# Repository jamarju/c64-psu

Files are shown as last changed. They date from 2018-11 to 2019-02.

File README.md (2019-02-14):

# C64 power supply unit

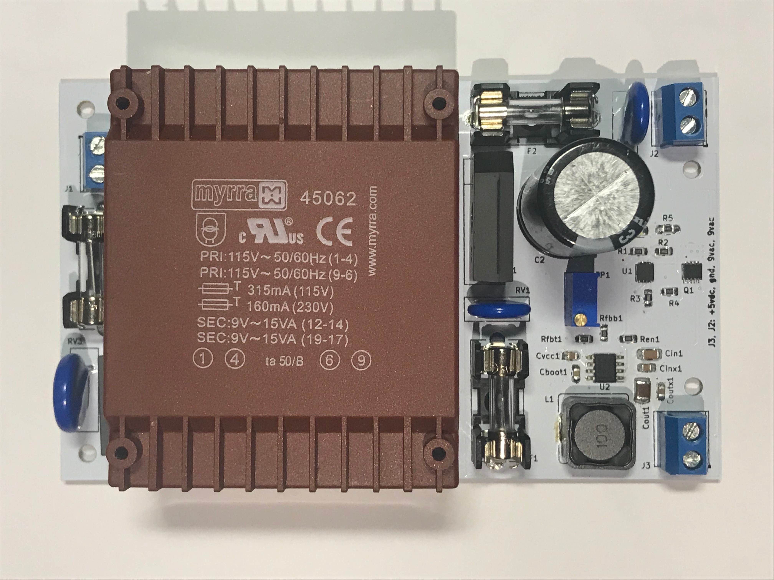
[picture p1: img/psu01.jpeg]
pcb view


This is a compact and efficient 9VAC/5VDC power supply for the Commodore 64 with the following features:

* 230VAC input (but easy to modify for 115VAC operation).
* 5 VDC output, adjustable, 1.75A max.
* 9 VAC output, 1.67A max.
* 6.5 VDC overvoltage protection (latching).
* Low VDC output ripple (<25 mV<sub>pp</sub> @1A).
* 2A overcurrent protection.
* Low heat dissipation.
* Mains overvoltage and noise suppresion.

## Building, warnings and recommendations

The kicad-project/gerbers folder contains gerber files ready for production. These are my recommended PCB specifications:

* 1.6 mm PCB thickness
* 2 oz copper thickness
* Min track / clearance: 8 mil

Beware there are three SMD components with thermal pads on the base that can't be easily soldered with a regular iron. You'll need **solder paste and an oven or a heat gun for these**.

## 110VAC operation

To work at 110 VAC, do these modifications to the schematic:

1. Connect the two primaries of TR1 in parallel instead of series:
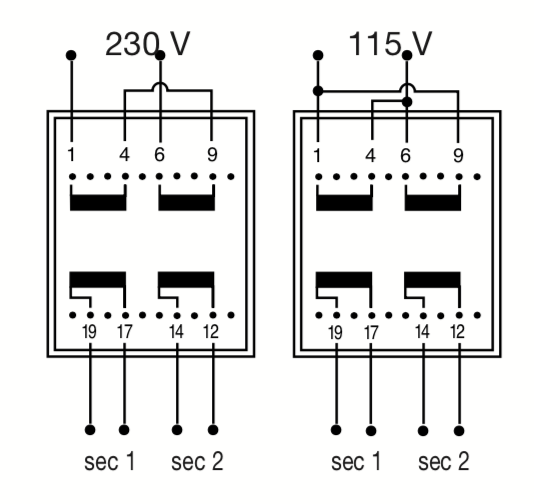
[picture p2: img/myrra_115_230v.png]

2. Replace RV3 (EPCOS 300 Vrms MOV) with EPCOS B72214S0151K101 (150 Vrms MOV).
3. Replace F3 (160 mA fuse) with 315 mA fuse.

## Adjusting 5VDC output

Start adjusting trimpot TP1 to get 5 VDC with no load.

Then check the voltage at the C64 input with the computer on. You should expect a bit less than 5V due to losses depending on the cable gauge and DIN connectors. Ideally you should aim at 5.0V but a bit of undervoltage (4.9V) appears to work okay on my C64 and will lower heat dissipation.

Output voltage can be adjusted in the [4.13V, 5.55V] range.

## Enclosure

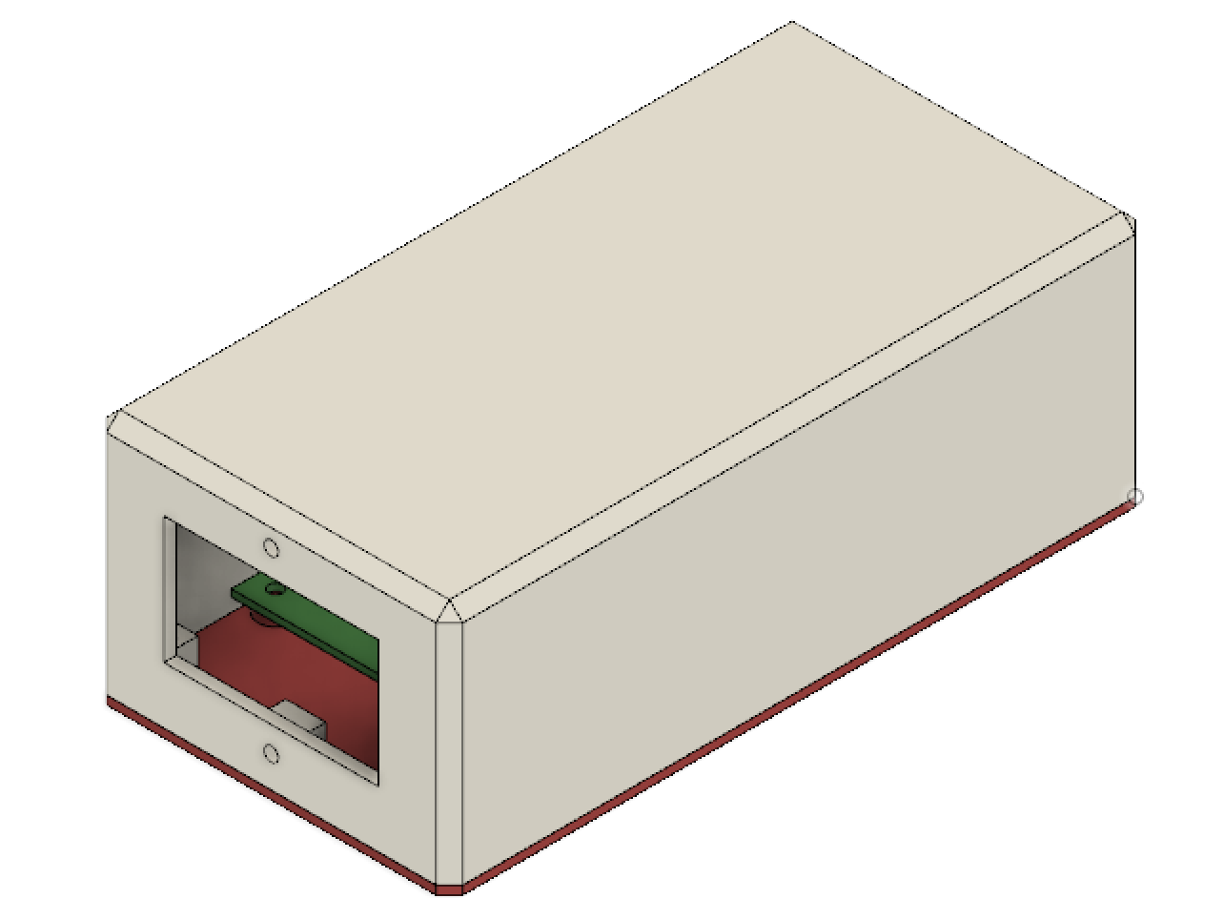
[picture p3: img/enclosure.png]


STLs and Fusion 360 project included in the enclosure/ folder. Sorry FreeCAD, I tried to keep this opensource but bodies in 0.17 are just not mature enough and doing this in 0.16 was too painful.

### Printing recommendations

* The bottom side can be printed bottom side flat on the printer bed without support.
* The top cover can be printed top side flat on the bed with supports everywhere.
* Material: I recommend PETG because of its higher melting temperature, great mechanical properties and low warping.
* I do not recommend PLA because of its low melting temperature.
* I do not recomment ABS either because of its high contraction ratio (= corner warp).

For the enclosure, in addition to the BOM components, you'll need:

* 6 x [Female quick disconnect 4.8 mm terminals](https://www.aliexpress.com/item/Free-shipping-100pcs-lot-4-8-insert-the-plug-spring-sheathed-wire-terminal-connector-cold-pressed/32593657279.html)
* 6 x [PCB male quick disconnect (aka spade) 4.8mm terminals](https://www.aliexpress.com/item/100pcs-4-8-Inserts-Plug-Spring-Terminal-PCB-Solder-lug-type-thickness-0-8mm-two-legs/32707189841.html) (these can replace the ones on the BOM and are much cheaper)
* 1 x [M12 PG7 strain relief](https://www.aliexpress.com/item/10pcs-Waterproof-M16-PG9-M12-PG7-Cable-Connectors-Spiral-Strain-Relief-Protector/32923675313.html)
* 1 x [Panel mount AC socket + rocking switch + fuse](https://www.aliexpress.com/item/Power-Rocker-Switch-IEC-3-Pin-320-C14-Inlet-Power-Sockets-Switch-Connector-Plug-10A-250V/32802047471.html)
* 1 x [4 cores, 5 meters 20 AWG cable](https://www.aliexpress.com/item/20-AWG-0-5MM2-RVV-2-3-4-5-6-7-8-10-12-14-16/32921926304.html)
* 1 x [7 pin male DIN connector (5 pcs minimum order)](https://www.aliexpress.com/item/5pcs-DIN-male-Plug-Connector-7-Pin-with-Plastic-Handle/32386538198.html)
* 10 x [M3x8 hex head bolts (100 units minimum order)](https://www.aliexpress.com/store/product/Free-Shipping-100pcs-Lot-Metric-Thread-DIN912-M3x8-mm-M3-8-mm-304-Stainless-Steel-Hex/3094064_32851042824.html)
* 10 x [M3 nuts (100 units min order)](https://www.aliexpress.com/item/Free-shipping-100pcs-lot-Metric-thread-DIN934-M3-304-Stainless-Steel-Hex-Nuts/32405600179.html)

### Cable length

I recommend keeping the C64-side cable as short and thick as possible. I recommend 20 AWG, 1 meter long wires.

The expected loss over 1 meter of 20 AWG wire at 5VDC and 1A is 33 mV per leg or 67 mV round trip.

## Schematic and protective measures



This PSU uses a 9VAC, 30VA dual secondary (15 VA + 15 VA) transformer that provides up to 1.67 amps on each secondary.

The regulator is a TI LMR33630 switching DC/DC step down converter with a switching frequency ~400 KHz and a peak efficiency of 93%.

To prevent an overvoltage situation due to failure of the swithing regulator or the feedback network, a MAX6399 voltage supervisor is used to control a high side P-channel MOSFET at the input of the switcher. When an overvoltage condition (V<sub>out</sub> >6.5V) is detected, the MAX6399 pulls the gate of the MOSFET down and cuts the regulator input until the power is completely removed from the unit.

The MAX6399 also provides undervoltage protection for clean startup of the switcher.

In addition to the over/undervoltage supervisor 3 varistors (MOVs) provide surge protection on the primary and both secondaries and 3 fuses prevent prolonged overcurrent condition on both sides of the transformer. The switcher itself also has an instant overcurrent protection above 3A.

## Tests

### Output ripple

Test conditions: V<sub>out</sub>=5.1V, I<sub>out</sub>=1A.

* Low frequency ripple: <20mV<sub>pp</sub>

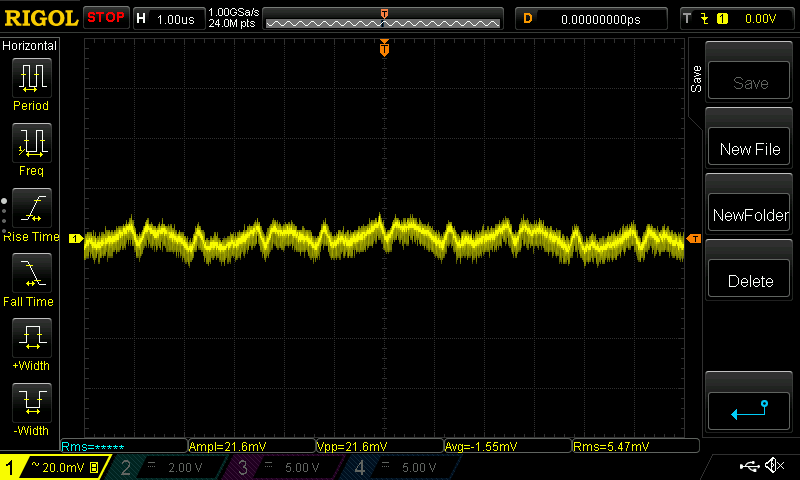
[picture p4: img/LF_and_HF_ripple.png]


### Overvoltage protection

Overvoltage protection voltage threshold set at V<sub>out</sub> >= 6.53V via R1/R2 divider.

Test conditions: shorted feedback input of LMR33630 to GND during normal operation at V<sub>out</sub>=5.1V, I<sub>out</sub>=1A.

@ 100 us per division:

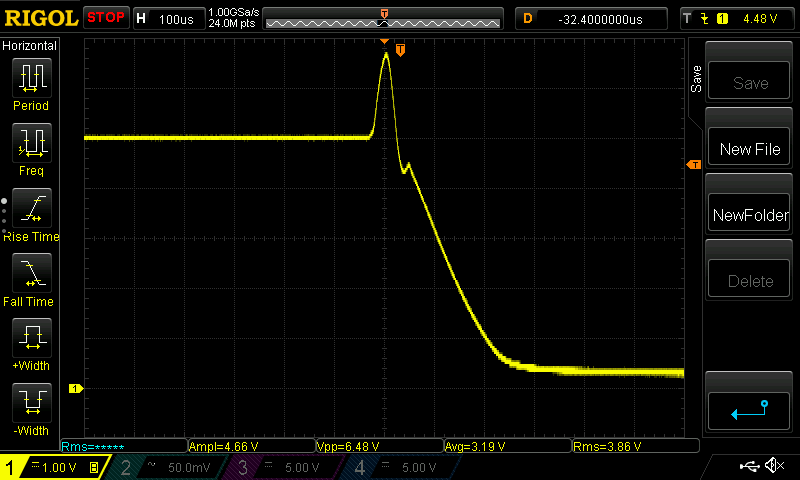
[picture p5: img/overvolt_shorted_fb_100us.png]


@ 10 us per division:

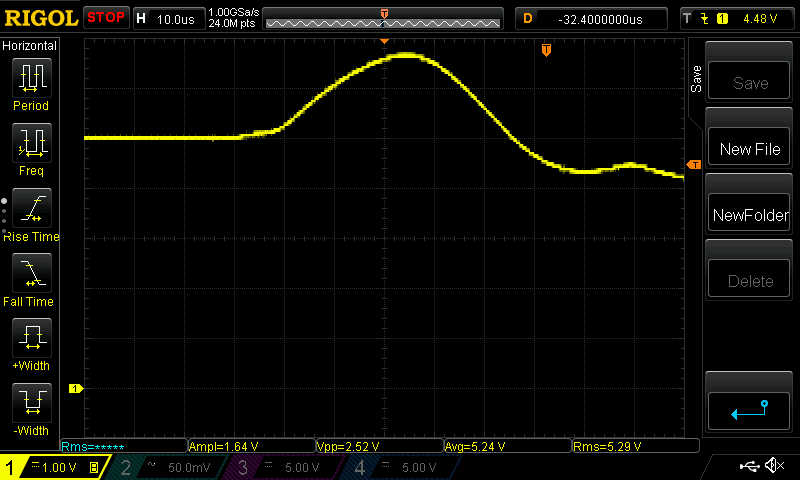
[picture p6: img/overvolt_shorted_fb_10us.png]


### Startup overshoot

Nominal V<sub>out</sub>: 5.10V
Overshoot: 5.36V (<10 ms)

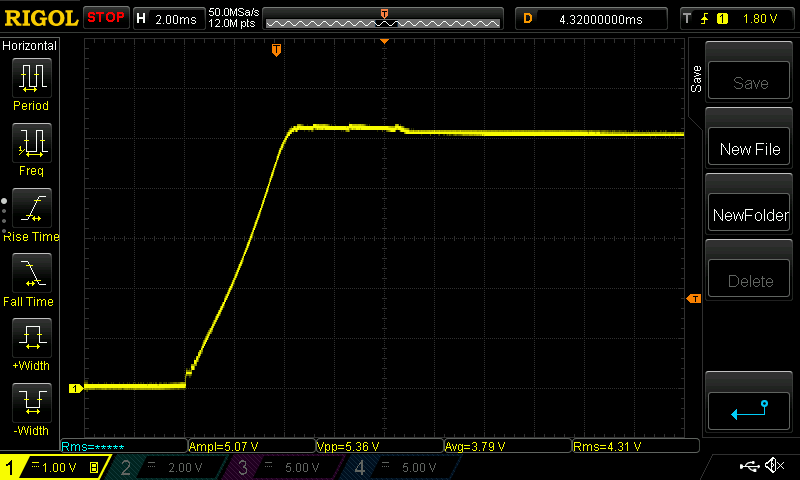
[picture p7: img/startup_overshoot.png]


### Power-ok and V<sub>out</sub> ramp-up

Undervoltage protection voltage threshold set at Vin <= 6.81V via R3/R4 divider.

* Yellow: V<sub>out</sub>
* Cyan: MAX6399 Power OK output (LMR33630 ENABLE input)

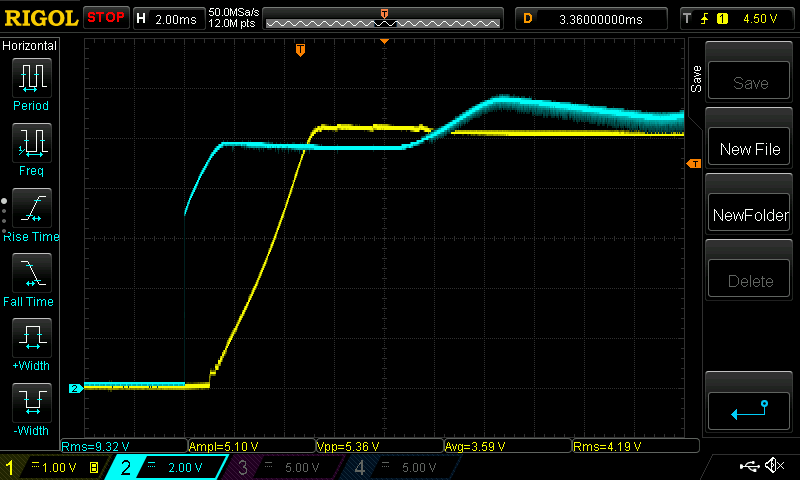
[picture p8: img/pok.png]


## TODO

* Actually test that this doesn't blow anything up. Tests should include at least:
  * Thermal behavior
  * Undervoltage POK (both edges)
  * Secondary-primary noise coupling
  * EMI emissions

## License

CC-BY-NC-SA (Attribution-NonCommercial-ShareAlike).

See LICENSE.txt for details.

Please do not mass (?) produce this without my permission.



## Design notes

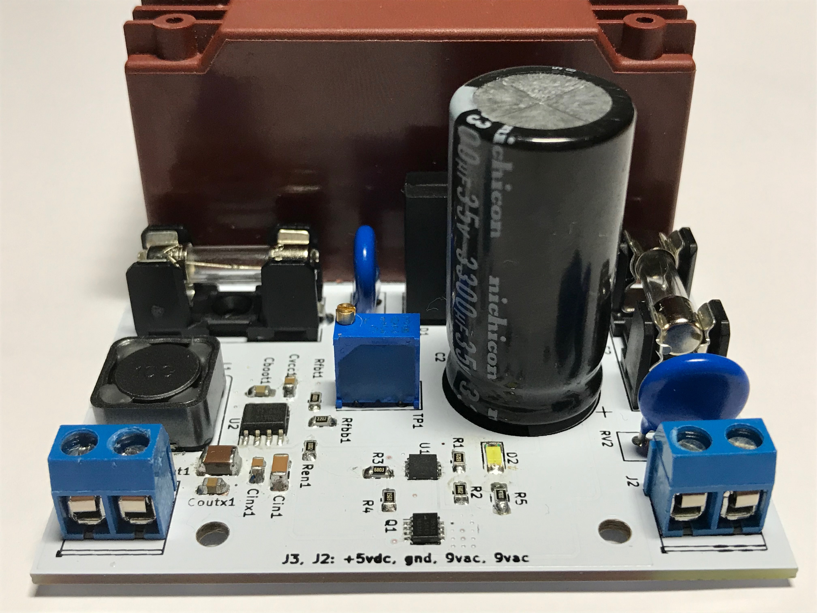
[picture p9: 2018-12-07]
img/psu04.jpeg

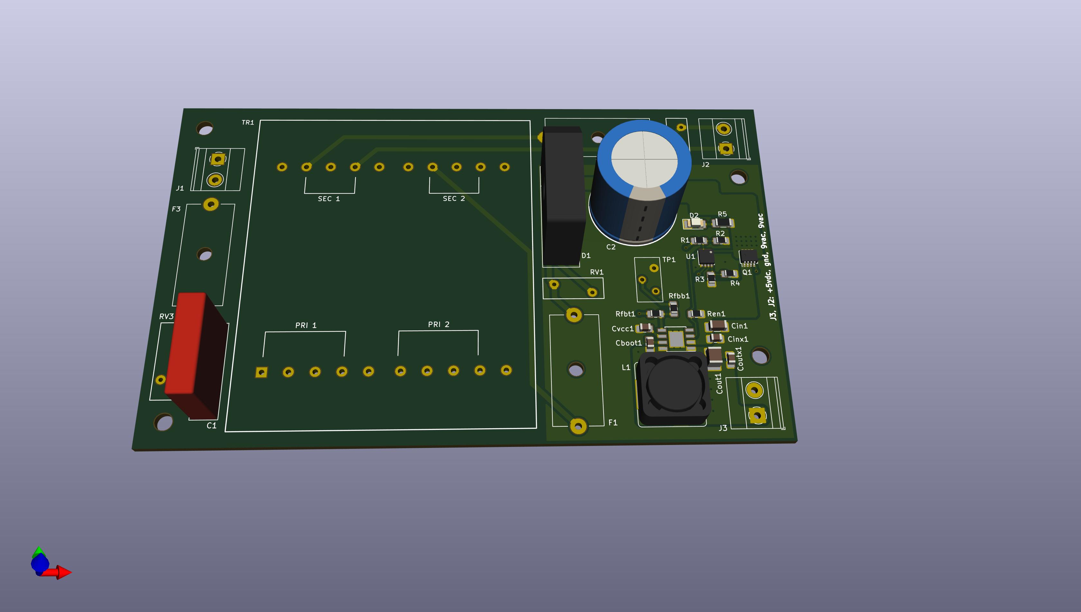
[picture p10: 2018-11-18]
img/render01.jpg

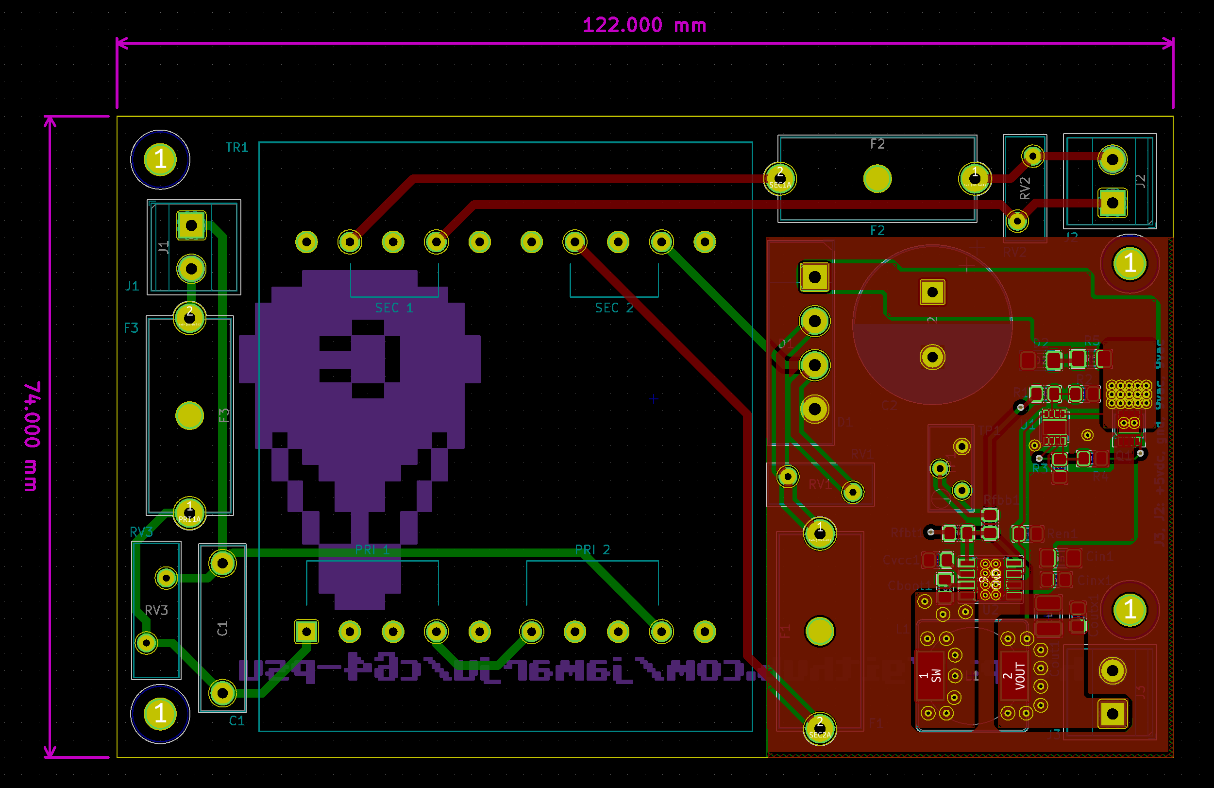
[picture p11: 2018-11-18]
img/pcb01.png

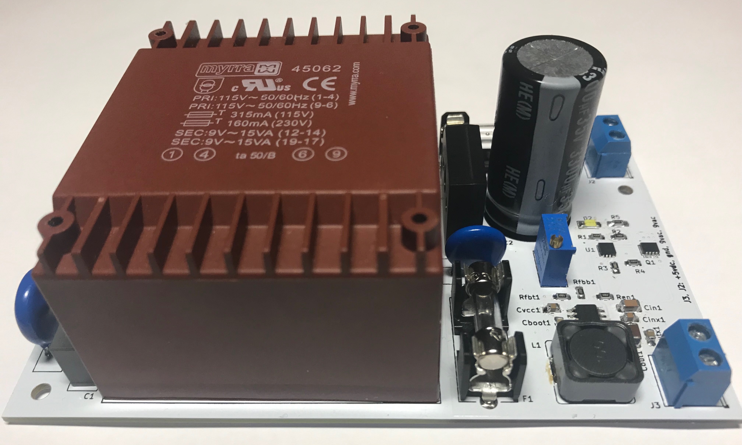
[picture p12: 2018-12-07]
img/psu02.jpeg

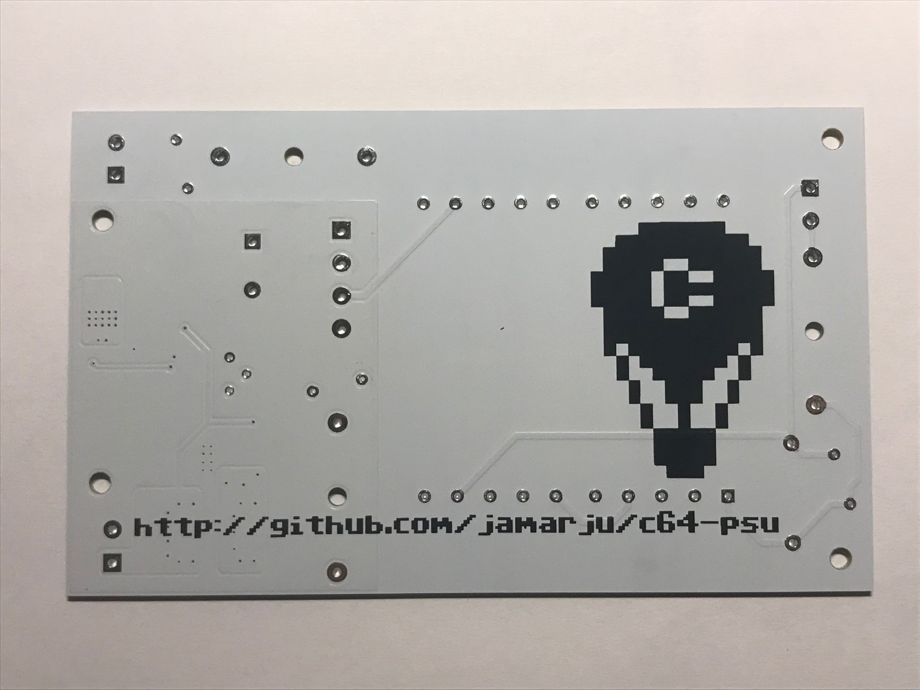
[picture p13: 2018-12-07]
img/psu03.jpeg

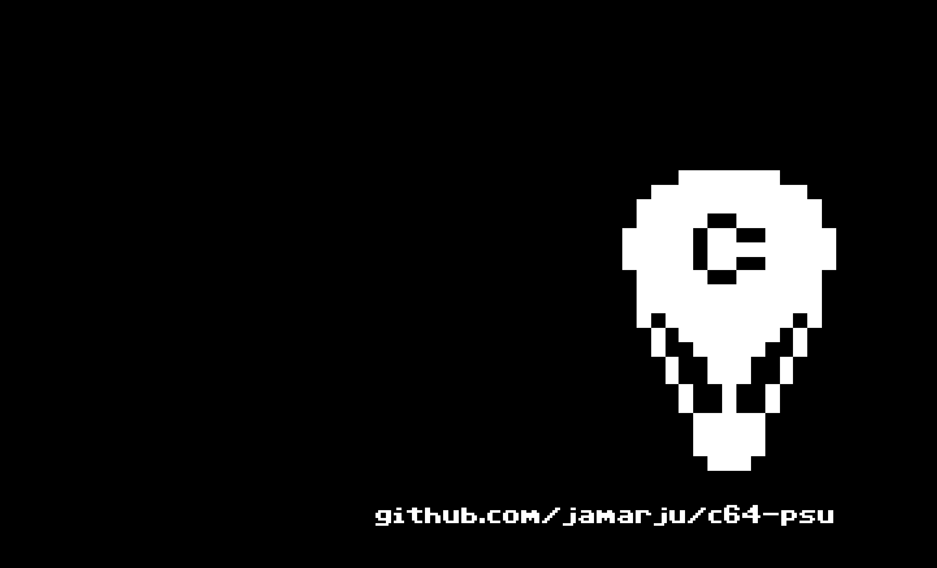
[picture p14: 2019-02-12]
art/linkballoon.png

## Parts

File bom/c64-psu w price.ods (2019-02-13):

Reference | Value | Footprint | Datasheet | Mfr | MfrCode | MouserCode | FarnellCode | Price
F2 | 1.67A | c64-psu:20mm fuse |  | Bel | 5ST 1.6-R | 530-5ST1.6-R |  | 0,172 €
F3 | 1.67A | c64-psu:20mm fuse |  | Bel | 5ST 1.6-R | 530-5ST1.6-R |  | 0,172 €
D1 | KBU8B | Diode_THT:Diode_Bridge_Vishay_KBU |  | GeneSiC | KBU8B | 905-KBU8B |  | 1,320 €
L1 | 10u | Inductor_SMD:L_Bourns_SRR1260 |  | Bourns | SRR1260-100M | 652-SRR1260-100M |  | 0,825 €
Rfbt1 | 100k | Resistor_SMD:R_0805_2012Metric_Pad1.15x1.40mm_HandSolder |  | Bourns | CR0805-FX-1003ELF | 652-CR0805FX-1003ELF |  | 0,013 €
Cout1 | 68u | Capacitor_SMD:C_1210_3225Metric_Pad1.42x2.65mm_HandSolder |  | TDK | C3225X5R0J686M200AC | 810-C3225X5R0J686M |  | 1,290 €
C2 | 3300u | Capacitor_THT:CP_Radial_D18.0mm_P7.50mm |  | Nichicon | UHE1V332MHD6 | 647-UHE1V332MHD6 |  | 2,180 €
U1 | LMR33630A | Package_SO:TI_SO-PowerPAD-8_ThermalVias |  | TI | LMR33630ADDAR | 595-LMR33630ADDAR |  | 3,210 €
Cboot1 | 100n | Capacitor_SMD:C_0805_2012Metric_Pad1.15x1.40mm_HandSolder |  | Yageo | CC0805KRX7R9BB104 | 603-CC805KRX7R9BB104 |  | 0,068 €
Rfbb1 | 22K | Resistor_SMD:R_0805_2012Metric_Pad1.15x1.40mm_HandSolder |  | Bourns | CR0805-FX-2202ELF | 652-CR0805-FX2202ELF |  | 0,013 €
Coutx3 | 1u | Capacitor_SMD:C_0805_2012Metric_Pad1.15x1.40mm_HandSolder |  | Murata | GRM21BR71A105KA01L | 81-GRM40X105K10L |  | 0,128 €
Cvcc1 | 1u | Capacitor_SMD:C_0805_2012Metric_Pad1.15x1.40mm_HandSolder |  | KEMET | C0805C105K8PACTU | 80-C0805C105K8P |  | 0,208 €
Cin1 | 10u | Capacitor_SMD:C_1206_3216Metric_Pad1.42x1.75mm_HandSolder |  | TDK | C3216X6S1V106K160AC | 810-C3216X6S1V106K6A |  | 0,374 €
Cinx1 | 220n | Capacitor_SMD:C_0805_2012Metric_Pad1.15x1.40mm_HandSolder |  | KEMET | C0805C224K5RACTM | 80-C0805C224K5RACTM |  | 0,111 €
F1 | 160mA | c64-psu:20mm fuse |  | Bel | 5ST 160-R | 530-5ST160-R |  | 0,172 €
RV1 | S14K300 | Varistor:RV_Disc_D15.5mm_W5.2mm_P7.5mm |  | EPCOS / TDK | B72214S301K101 | 871-B72214S301K101 |  | 0,326 €
C1 | 10n | Capacitor_THT:C_Rect_L19.0mm_W5.0mm_P15.00mm_MKS4 |  | KEMET | R46KI21004001K1 | 80-R46KI21004001K1 |  | 0,199 €
RV3 | S10K20 | Varistor:RV_Disc_D12mm_W4.5mm_P7.5mm |  | EPCOS / TDK | B72210S200K101 | 871-B72210S200K101 |  | 0,304 €
RV2 | S10K20 | Varistor:RV_Disc_D12mm_W4.5mm_P7.5mm |  | EPCOS / TDK | B72210S200K101 | 871-B72210S200K101 |  | 0,304 €
TRIM1 | 10K | Potentiometer_THT:Potentiometer_Bourns_3296Y_Vertical |  | Bourns | PV36Y103C01B00 | 81-PV36Y103C01B00 |  | 0,969 €
TR1 | Myrra_UI_39_TRF | c64-psu:Myrra UI 39 trf |  | Myrra | UI 39 |  | 1777965 | 11,900 €
R2 | 820k | Resistor_SMD:R_0805_2012Metric_Pad1.15x1.40mm_HandSolder |  | Bourns | CR0805-FX-8203ELF | 652-CR0805FX-8203ELF |  | 0,013 €
R4 | 68k | Resistor_SMD:R_0805_2012Metric_Pad1.15x1.40mm_HandSolder |  | Bourns | CR0805-FX-6802ELF | 652-CR0805FX-6802ELF |  | 0,013 €
U2 | MAX6399 | Package_DFN_QFN:DFN-8-1EP_3x3mm_P0.65mm_EP1.55x2.4mm |  | Maxim | MAX6399ATA+T | 700-MAX6399ATAT |  | 2,240 €
R3 | 680k | Resistor_SMD:R_0805_2012Metric_Pad1.15x1.40mm_HandSolder |  | Bourns | CR0805-FX-6803ELF | 652-CR0805FX-6803ELF |  | 0,013 €
Ren1 | 10k | Resistor_SMD:R_0805_2012Metric_Pad1.15x1.40mm_HandSolder |  | Bourns | CR0805-FX-1002ELF | 652-CR0805FX-1002ELF |  | 0,013 €
R5 | 150k | Resistor_SMD:R_0805_2012Metric_Pad1.15x1.40mm_HandSolder |  | Bourns | CR0805-FX-1503ELF | 652-CR0805FX-1503ELF |  | 0,065 €
R1 | 4K7 | Resistor_SMD:R_1206_3216Metric_Pad1.42x1.75mm_HandSolder |  | Bourns | CR1206-FX-4701ELF | 652-CR1206FX-4701ELF |  | 0,013 €
Q1 | N-MOS | c64-psu:LFPAK33-PSMN7R5-30MLD |  | Nexperia | PSMN7R5-30MLD | 771-PSMN7R5-30MLDX |  | 0,338 €
XF3 | 1.67A | Fuse:Fuseholder_Cylinder-5x20mm_Schurter_0031_8201_Horizontal_Open |  | Schurter | 0031.8201 | 693-0031.8201 |  | 0,466 €
XF2 | 1.67A | Fuse:Fuseholder_Cylinder-5x20mm_Schurter_0031_8201_Horizontal_Open |  | Schurter | 0031.8201 | 693-0031.8201 |  | 0,466 €
XF1 | 160 mA | Fuse:Fuseholder_Cylinder-5x20mm_Schurter_0031_8201_Horizontal_Open |  | Schurter | 0031.8201 | 693-0031.8201 |  | 0,466 €
D2 | LED | LED_SMD:LED_1206_3216Metric_Pad1.42x1.75mm_HandSolder |  | Any | Aliexpress: '1206 white led' |  |  | 0,010 €
Coutx2 | 1u | Capacitor_SMD:C_0805_2012Metric_Pad1.15x1.40mm_HandSolder |  | Murata | GRM21BR71A105KA01L | 81-GRM40X105K10L
Coutx1 | 1u | Capacitor_SMD:C_0805_2012Metric_Pad1.15x1.40mm_HandSolder |  | Murata | GRM21BR71A105KA01L | 81-GRM40X105K10L |  | 0,128 €
J5 | Conn_01x01 | c64-psu:spade_4.8mm |  | Keystone | 1212-ST | 534-1212-ST |  | 0,147 €
J6 | Conn_01x01 | c64-psu:spade_4.8mm |  | Keystone | 1212-ST | 534-1212-ST |  | 0,147 €
J4 | Conn_01x01 | c64-psu:spade_4.8mm |  | Keystone | 1212-ST | 534-1212-ST |  | 0,147 €
J1 | Conn_01x01 | c64-psu:spade_4.8mm |  | Keystone | 1212-ST | 534-1212-ST |  | 0,147 €
J2 | Conn_01x01 | c64-psu:spade_4.8mm |  | Keystone | 1212-ST | 534-1212-ST |  | 0,147 €
J3 | Conn_01x01 | c64-psu:spade_4.8mm |  | Keystone | 1212-ST | 534-1212-ST |  | 0,147 €
 |  |  |  |  |  |  |  | 29,384 €

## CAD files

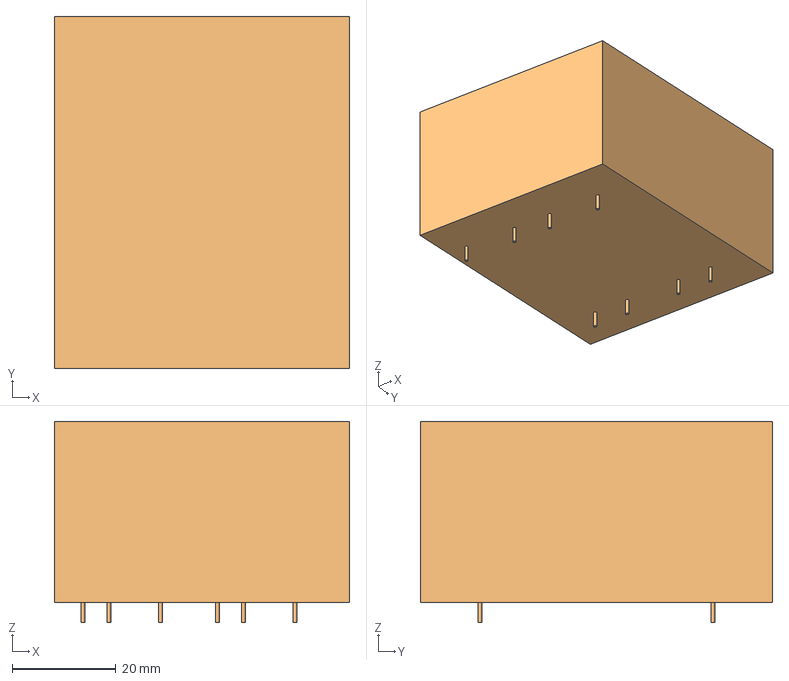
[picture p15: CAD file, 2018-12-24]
cad/Myrra_UI_39x21_30VA.FCStd
57.0 x 68.0 x 38.9 mm

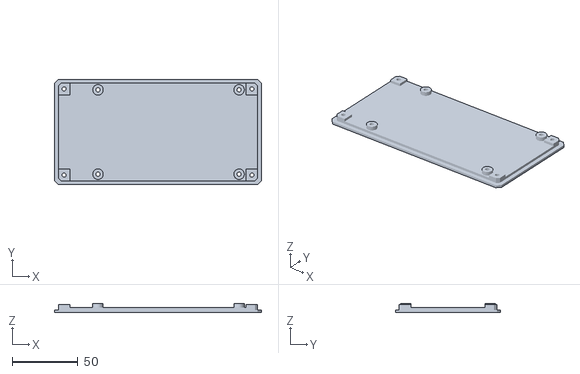
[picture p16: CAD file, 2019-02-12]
enclosure/c64-psu-bottom-v2018.2.stl
157.0 x 80.0 x 7.00

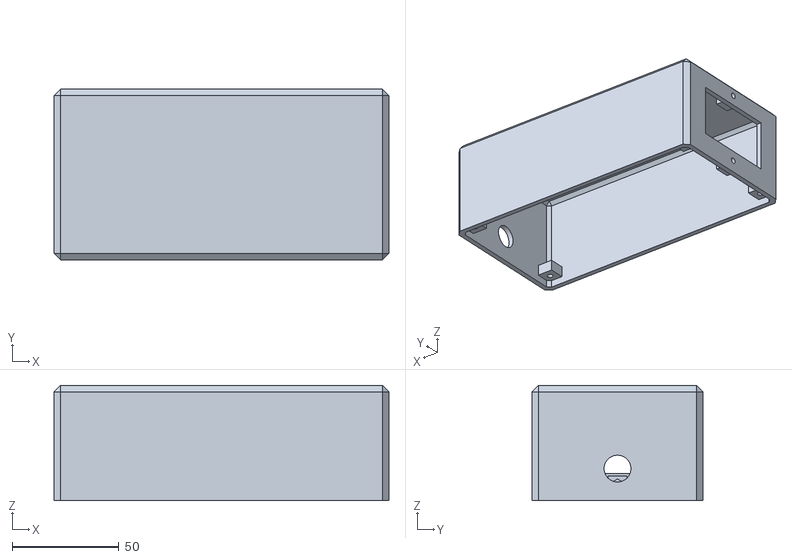
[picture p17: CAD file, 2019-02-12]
enclosure/c64-psu-top-v2018.2.stl
157.0 x 80.0 x 54.0

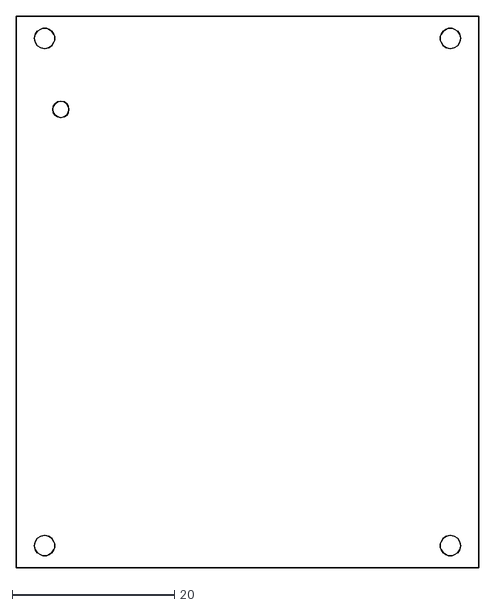
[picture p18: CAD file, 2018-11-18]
cad/myrra ui 39 footprint.dxf
57.0 x 68.0

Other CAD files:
cad/footprints.FCStd
enclosure/c64-psu-2018.2 v1.f3d

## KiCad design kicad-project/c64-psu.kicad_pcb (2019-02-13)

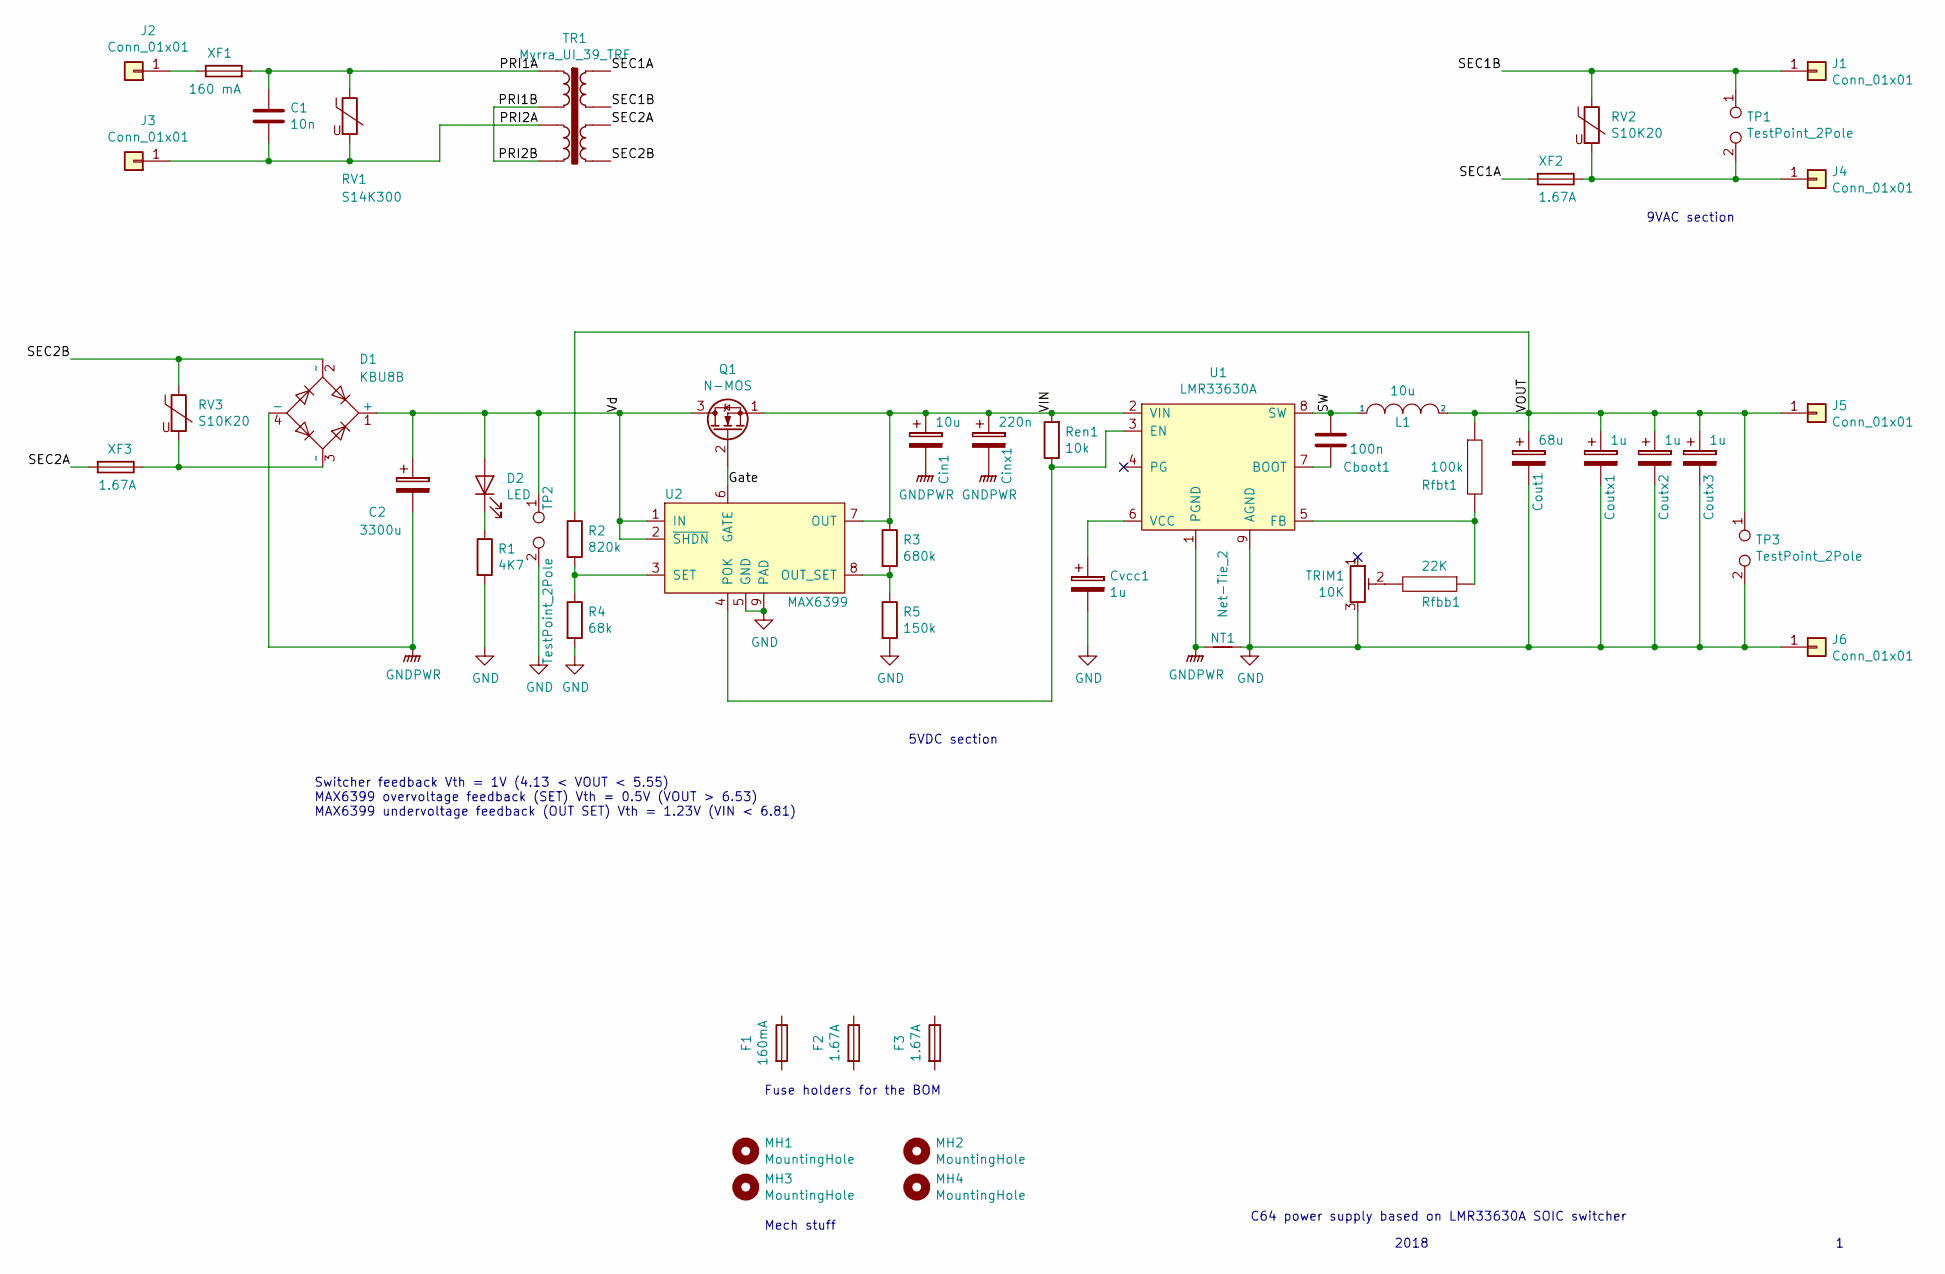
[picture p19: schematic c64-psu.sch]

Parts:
C1: 10n; C_Rect_L19.0mm_W5.0mm_P15.00mm_MKS4; MouserCode 80-R46KI21004001K1
C2: 3300u; CP_Radial_D18.0mm_P7.50mm; MouserCode 647-UHE1V332MHD6
Cboot1: 100n; C_0805_2012Metric_Pad1.15x1.40mm_HandSolder; MouserCode 603-CC805KRX7R9BB104
Cin1: 10u; C_1206_3216Metric_Pad1.42x1.75mm_HandSolder; MouserCode 810-C3216X6S1V106K6A
Cinx1: 220n; C_0805_2012Metric_Pad1.15x1.40mm_HandSolder; MouserCode 80-C0805C224K5RACTM
Cout1: 68u; C_1210_3225Metric_Pad1.42x2.65mm_HandSolder; MouserCode 810-C3225X5R0J686M
Coutx1, Coutx2, Coutx3: 1u; C_0805_2012Metric_Pad1.15x1.40mm_HandSolder; MouserCode 81-GRM40X105K10L
Cvcc1: 1u; C_0805_2012Metric_Pad1.15x1.40mm_HandSolder; MouserCode 80-C0805C105K8P
D1: KBU8B; Diode_Bridge_Vishay_KBU; MouserCode 905-KBU8B
D2: LED; LED_1206_3216Metric_Pad1.42x1.75mm_HandSolder
F1: 160mA; 20mm fuse; MouserCode 530-5ST160-R
F2, F3: 1.67A; 20mm fuse; MouserCode 530-5ST1.6-R
J1, J2, J3, J4, J5, J6: Conn_01x01; spade_4.8mm; MouserCode 534-1212-ST
L1: 10u; L_Bourns_SRR1260; MouserCode 652-SRR1260-100M
MH1, MH2, MH3, MH4: MountingHole; MountingHole_3.2mm_M3
NT1: Net-Tie_2; NetTie-2_THT_Pad1.0mm
Q1: N-MOS; LFPAK33-PSMN7R5-30MLD; MouserCode 771-PSMN7R5-30MLDX
R1: 4K7; R_1206_3216Metric_Pad1.42x1.75mm_HandSolder; MouserCode 652-CR1206FX-4701ELF
R2: 820k; R_0805_2012Metric_Pad1.15x1.40mm_HandSolder; MouserCode 652-CR0805FX-8203ELF
R3: 680k; R_0805_2012Metric_Pad1.15x1.40mm_HandSolder; MouserCode 652-CR0805FX-6803ELF
R4: 68k; R_0805_2012Metric_Pad1.15x1.40mm_HandSolder; MouserCode 652-CR0805FX-6802ELF
R5: 150k; R_0805_2012Metric_Pad1.15x1.40mm_HandSolder; MouserCode 652-CR0805FX-1503ELF
RV1: S14K300; RV_Disc_D15.5mm_W5.2mm_P7.5mm; MouserCode 871-B72214S301K101
RV2, RV3: S10K20; RV_Disc_D12mm_W4.5mm_P7.5mm; MouserCode 871-B72210S200K101
Ren1: 10k; R_0805_2012Metric_Pad1.15x1.40mm_HandSolder; MouserCode 652-CR0805FX-1002ELF
Rfbb1: 22K; R_0805_2012Metric_Pad1.15x1.40mm_HandSolder; MouserCode 652-CR0805-FX2202ELF
Rfbt1: 100k; R_0805_2012Metric_Pad1.15x1.40mm_HandSolder; MouserCode 652-CR0805FX-1003ELF
TP1, TP2, TP3: TestPoint_2Pole; TestPoint_2Pads_Pitch2.54mm_Drill0.8mm
TR1: Myrra_UI_39_TRF; Myrra UI 39 trf; FarnellCode 1777965
TRIM1: 10K; Potentiometer_Bourns_3296Y_Vertical; MouserCode 81-PV36Y103C01B00
U1: LMR33630A; TI_SO-PowerPAD-8_ThermalVias; MouserCode 595-LMR33630ADDAR
U2: MAX6399; DFN-8-1EP_3x3mm_P0.65mm_EP1.55x2.4mm; MouserCode 700-MAX6399ATAT
XF1: 160 mA; Fuseholder_Cylinder-5x20mm_Schurter_0031_8201_Horizontal_Op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; MouserCode 693-0031.8201
XF2, XF3: 1.67A; Fuseholder_Cylinder-5x20mm_Schurter_0031_8201_Horizontal_Op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; MouserCode 693-0031.8201

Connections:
/Gate: Q1.2 (G), U2.6 (GATE)
/PRI1A: C1.1, RV1.1, TR1.1, XF1.2
/PRI1B: TR1.4, TR1.9
/PRI2A: C1.2, J3.1, RV1.2, TR1.6
/SEC1A: TR1.19, XF2.2
/SEC1B: J1.1, RV2.1, TP1.1, TR1.17
/SEC2A: TR1.14, XF3.2
/SEC2B: D1.2 (~~), RV3.1, TR1.12
/SW: Cboot1.2, L1.1, U1.8 (SW)
/VIN: Cin1.1, Cinx1.1, Q1.1 (S), R3.1, Ren1.2, U1.2 (VIN), U2.7 (OUT)
/VOUT: Cout1.1, Coutx1.1, Coutx2.1, Coutx3.1, J5.1, L1.2, R2.1, Rfbt1.1, TP3.1
/Vd: C2.1, D1.1 (+), D2.2 (A), Q1.3 (D), TP2.1, U2.1 (IN), U2.2 (~SHDN)
GND: Cout1.2, Coutx1.2, Coutx2.2, Coutx3.2, Cvcc1.2, J6.1, NT1.2, R1.2, R4.2, R5.2, TP2.2, TP3.2, TRIM1.3, U1.9 (AGND), U2.5 (GND), U2.9 (PAD)
GNDPWR: C2.2, Cin1.2, Cinx1.2, D1.4 (-), NT1.1, U1.1 (PGND)
unnamed: Cboot1.1, U1.7 (BOOT)
unnamed: Cvcc1.1, U1.6 (VCC)
unnamed: D1.3 (~~), RV3.2, XF3.1
unnamed: D2.1 (K), R1.1
unnamed: J2.1, XF1.1
unnamed: J4.1, RV2.2, TP1.2, XF2.1
unnamed: R2.2, R4.1, U2.3 (SET)
unnamed: R3.2, R5.1, U2.8 (OUT_SET)
unnamed: Ren1.1, U1.3 (EN), U2.4 (POK)
unnamed: Rfbb1.1, Rfbt1.2, U1.5 (FB)
unnamed: Rfbb1.2, TRIM1.2

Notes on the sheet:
C64 power supply based on LMR33630A SOIC switcher
2018
Fuse holders for the BOM
Mech stuff
9VAC section
5VDC section
Switcher feedback Vth = 1V (4.13 < VOUT < 5.55) MAX6399 overvoltage feedback (SET) Vth = 0.5V (VOUT > 6.53) MAX6399 undervoltage feedback (OUT SET) Vth = 1.23V (VIN < 6.81)

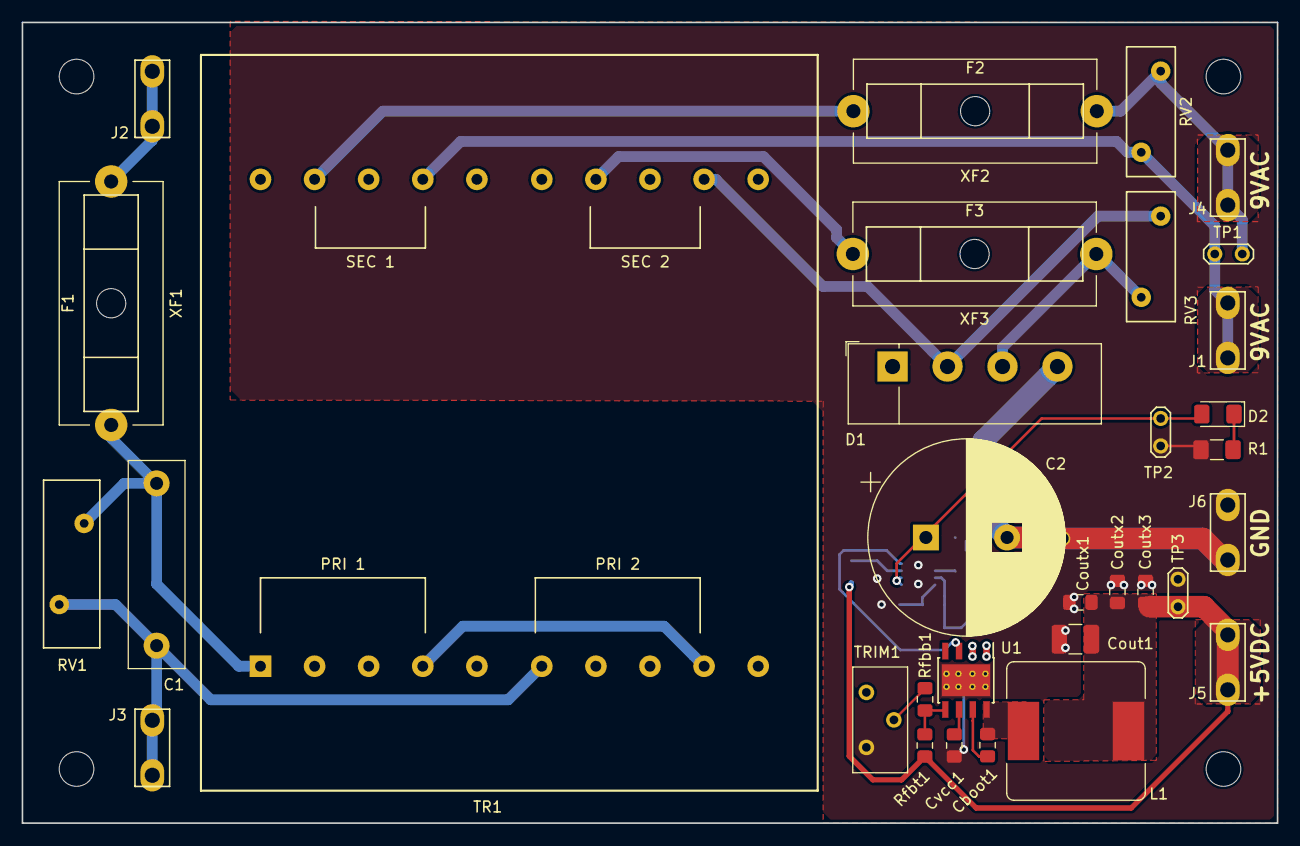
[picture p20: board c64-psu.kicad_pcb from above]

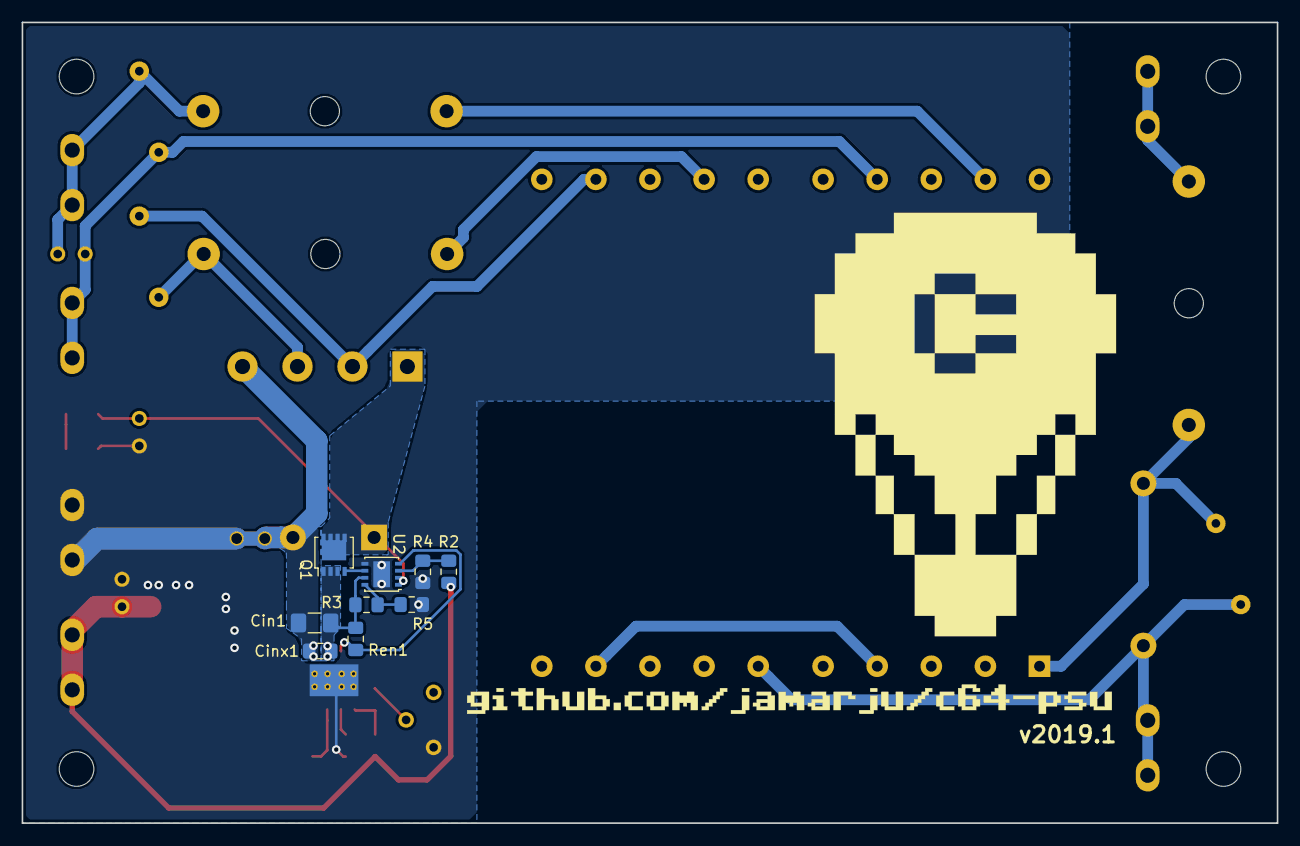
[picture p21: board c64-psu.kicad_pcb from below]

Board: 2 copper layers, 116.0 x 74.0 mm, 49 parts (9 on the bottom side), 25 nets.

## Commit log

2018-11-18 1st commit, untested design, lots of todos
    [c64-psu.csv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]
2018-11-18 replace " with ' in BOM
    [c64-psu.csv, c64-psu.sch]
2018-11-18 bom: manually remove mounting holes as their missing fields confuse github
    [c64-psu.csv]
2018-12-07 fix TR1 primary series connection (!!!), added voltage threshold comments on schematic, reversed J3 (when did that break?), added test captures,
    [c64-psu.kicad_pcb, c64-psu.sch]
2018-12-11 fix R5 value and MfrCode
    (was a 1206 10K but MfrCode was of a 0805 470 resistor). Also lowered original value of 10K to 4K7 to balance LED power waste vs overvoltage latch reset time
    [c64-psu.csv, c64-psu.sch]
2018-12-24 HF noise improvements (reduce high di/dt loop area, reduce SW node area, etc.).
    Also:
    + Moved trf's origin to pin 1
    + Replaced 5 mm pitch connectors with (apparently safer) 7.62 mm
    ToDo:
    - Could be further improved by fitting the switcher between the filter cap legs on the bottom side! Will try that next.
    [Myrra_UI_39x21_30VA.FCStd, Myrra_UI_39x21_30VA.step, c64-psu.kicad_pcb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]
2019-02-12 enclosure for v2018.1 (aka white PCB with trafo primary series bug)
    [enclosure.FCStd]
2019-02-12 v2018.2 ready for mfr
    + replaced terminal blocks with quick-disconnect / spade connectors +
    + added footprints for fuses
    + enclosure redone in fusion 3d (sorry freecad 0.17 bodies are not mature yet, I tried)
    + gerbers ready for prod
    [c64-psu-2018.2 v1.f3d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]
2019-02-12 added enclosure STLs
    [c64-psu-2018.2 v1.f3d, c64-psu-bottom-v2018.2.stl, c64-psu-top-v2018.2.stl]
2019-02-13 fixed bug: copper fill under spade connectors to prevent ground plane shorts
    gerbers + bom redone
    [c64-psu-B.Cu.gbl, c64-psu-B.Mask.gbs, c64-psu-B.SilkS.gbo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]
2019-02-13 added license, enclosure render + additional parts links
    [c64-psu w price.ods]
2019-02-13 added schematic to the README
2019-02-14 added enclosure related BOM + caution on SMD soldering, cable length recommendations, etc.
